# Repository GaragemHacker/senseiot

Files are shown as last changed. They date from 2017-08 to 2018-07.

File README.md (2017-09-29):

senseiot
========

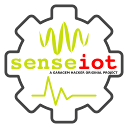
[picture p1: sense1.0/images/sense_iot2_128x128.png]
(https://github.com/Garagem-Hacker/senseiot/)
.

Sense IoT é um projeto para pesquisa e desenvolvimento de uma rede de sensores sem fio.

Sensores
--------

* **ht**: Umidade e temperatura.
* **sound**: Som.
* **presence**: Presença.
* **gas**: Gás.
* **rain**: Chuva.

ESP8266
-------

Vamos utilizar o ESP8266 neste projeto.
Veja o wiki para uma introdução ao
[ESP8266](https://github.com/Garagem-Hacker/senseiot/wiki).

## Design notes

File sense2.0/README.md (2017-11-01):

Senseiot 2.0
============
Nova Versão de Sense IoT

(https://github.com/Garagem-Hacker/senseiot/).

Sense IoT é um projeto para pesquisa e desenvolvimento de uma rede de sensores sem fio.

Hardware
--------
* **ESP8266**: Nó IoT;
* **Raspberry**: Gateway IoT;
* **ht05**: Sensor de Umidade e Temperatura;
* **sct**: Sensor de Corrente Elétrica;
* **ASQ/Ctrl-Board**: Aquisição de corrente e Comandos elétricos.
* NodeMCU: Nó Lora com sensores BMP085 e TSL2561.

Software
--------
* **API**: Da acesso do banco de dados ao Servidor Mathematica
* **Crypto**: Encript/Decrypt Payload
* **Docker**: Docker Containers
* **Mathematica**: Computer Algebra System (CAS) para Analytics dos dados
* **WebPage**: Visualização dos dados coletados e comandos para controle.

Ferramentas
-----------
* **BrokerMQTT**: Servidor IoT MQTT
* **Flask**: Microframework para aplicação Web
* **Docker**: Docker Containers
* **Crypto**: Rotinas para Criptografar/Decriptografar dados

Estrutura MQTT
--------------
Regra de comunicação dos tópicos MQTT para os dispositivos

/*		   MQTT Topic Struct

 	    'dev/node1/current2'
		|    |     |
		|    |     |
  	device(dev)  |    variable to sub/pub 
  		or   | (led1..n,temp1...n,button1...n)
 		     |
	command(cmd) |
 		     |
	IoT device node (node1...n)

*/

 Em resumo:
* Classe dispositivos(dev) ou comandos (cmd)
* Nó IoT em Questão (node1,..n)
* Variavel de Controle/Comandos (led1, button2, temp1, ...)

Dockers Containers
------------------
* **dMosquitto**: Mosquitto MQTT
* **dFlask**: Servico Backend
...

Referências 
-----------

 * [ESP8266](https://github.com/Garagem-Hacker/senseiot/wiki) - Utilização do ESP8266;
 * [ESP8266-&-MQTT](https://github.com/edgarreis/ESP8266-MQTT-Arduino) - Utilização do MQTT no ESP8266;
 * [MQTT-Python-Web](https://douglaszuqueto.com/artigos/integrando-a-aplicacao-web-com-banco-de-dados) - Integrando a aplicação MQTT à web com banco de dados;

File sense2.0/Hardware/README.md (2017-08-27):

senseiot
========

Placas de Monitoramento de Consumo e Comando.

Schematic
-------
***CurrentMeasBoard**

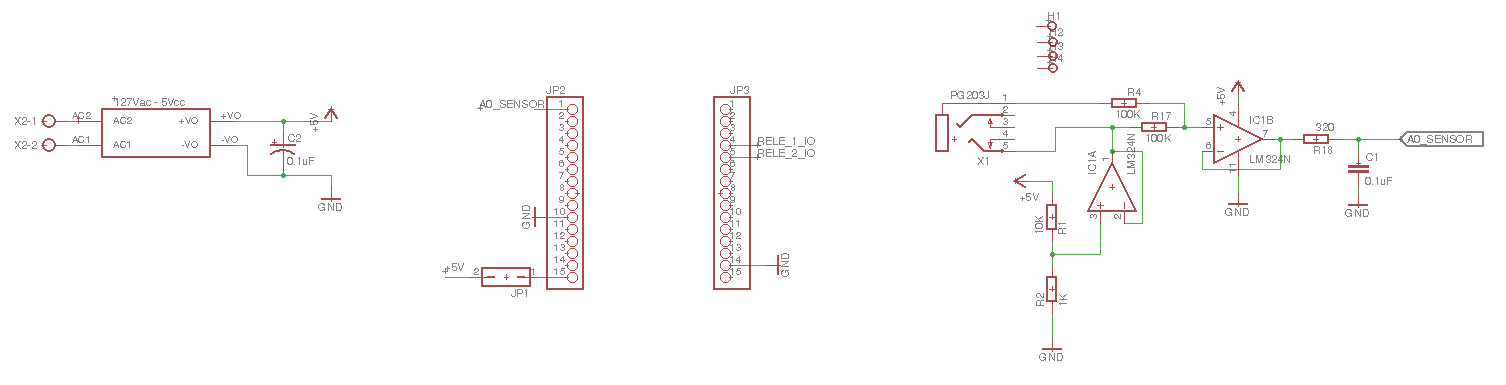
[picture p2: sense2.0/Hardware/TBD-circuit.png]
(https://github.com/Garagem-Hacker/senseiot/)


***RelesBoard**

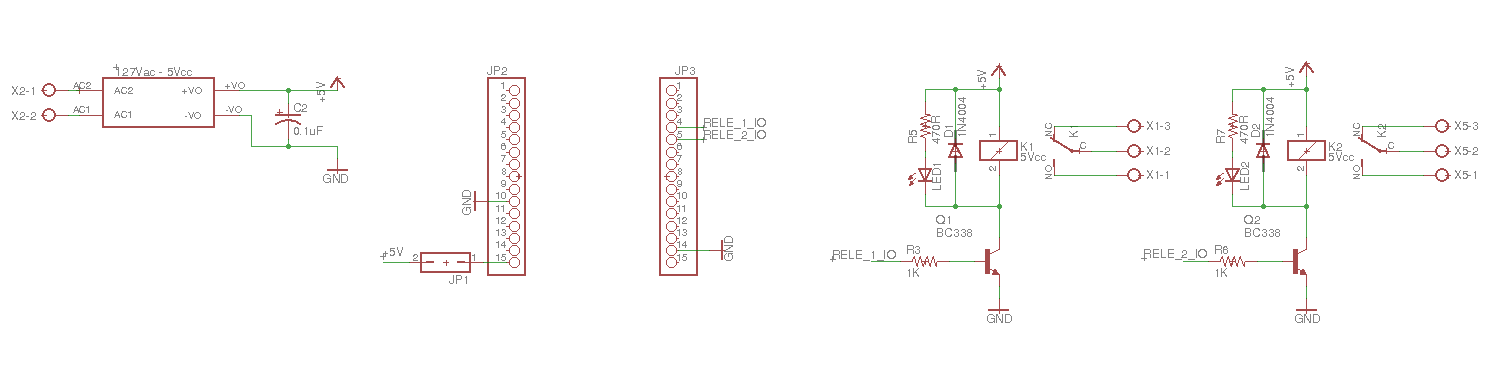
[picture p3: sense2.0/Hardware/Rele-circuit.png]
(https://github.com/Garagem-Hacker/senseiot/)


Board
-----

***CurrentMeasBoard**

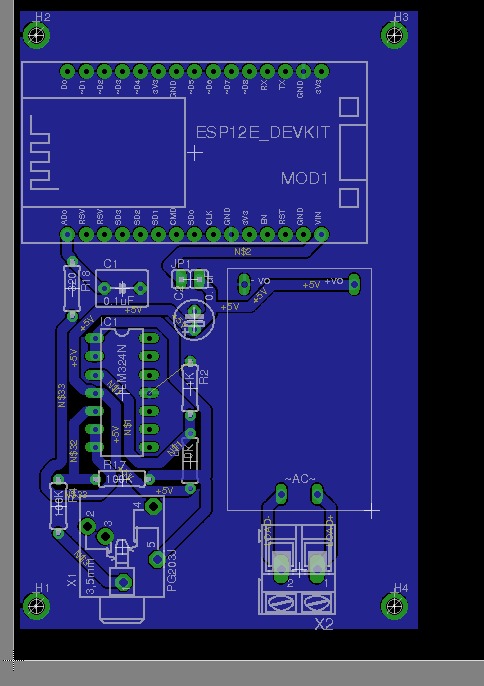
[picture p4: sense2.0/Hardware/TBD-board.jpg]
(https://github.com/Garagem-Hacker/senseiot/)


***RelesBoard**

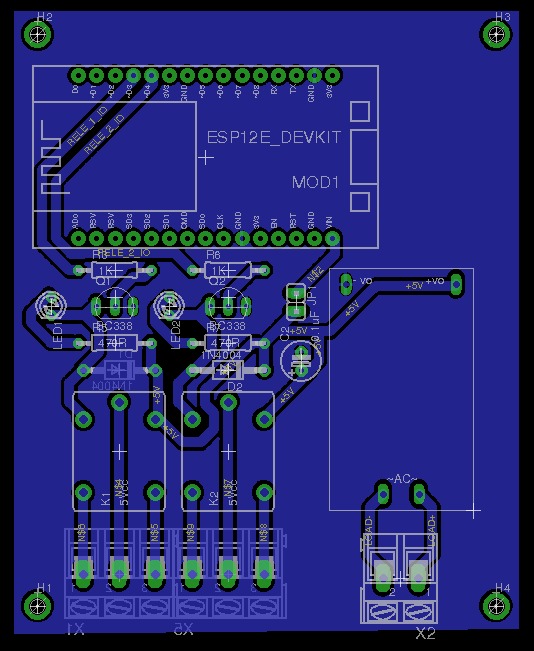
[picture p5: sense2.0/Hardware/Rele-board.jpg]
(https://github.com/Garagem-Hacker/senseiot/)


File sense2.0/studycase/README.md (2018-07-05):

### StudyCase

This is the iot.garagemhacker.org which wee have present a simple use case of IOT's Up and Running  
with a go website desplaying grafs of a set o sensors controled by a bunch of ESP8266 nodeMcu nodes.
  
Deploy me with traefik as a rev-proxy then compose me up. :wink:  
Enjoy

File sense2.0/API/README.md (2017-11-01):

# API para Acesso dos dados do Banco de Dados
-------------------

Funcionalidades
---------------

* **create_table.py** Cria as Tabelas do SQLite

* **database.db** Database em SQLite que persiste os dados trocados entre o MQTT e a API 

* **subscriber.py** Descontinuado (~~Subscreve nos Tópicos MQTT e salva os dados no Banco de Dados~~)

* **publish_subscribe.py** Subscreve nos Tópicos MQTT e salva os dados no Banco de Dados, além de Publicar os dados novos no banco de dados que são recebidos pela API

* **rest_flask.py** Descontinuado (~~Coleta do banco os dados e repassa via método GET, Informações: Temperatura~~)

* **rest_flask2.py** Descontinuado (~~Coleta do banco os dados e repassa via método GET, Informações: Temperatura e Corrente~~)

* **restful_flask.py** API - Coleta do banco os dados e repassa via método GET, além de receber os dados vai método POST. Informações: Temperatura, Corrente, Comando (Separados via nós).

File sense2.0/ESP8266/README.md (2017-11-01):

# ESP8266 Codes
-------------------

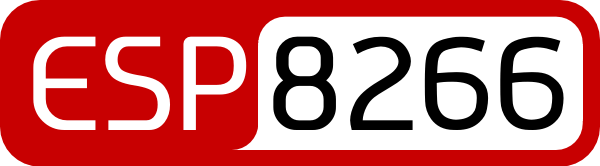
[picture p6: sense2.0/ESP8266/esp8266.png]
(https://github.com/Garagem-Hacker/senseiot/)
.

* **CurrentMeas.ino** Faz Medições de Corrente com Sct-013-100 

* **Dht22_mqtt.ino** Faz Medições de Temperatura e Umidade com o DHT22

* **Reles_mqtt.ino** Atua em dispositivos ON/OFF

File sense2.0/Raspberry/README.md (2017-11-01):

# Raspberry
-------------

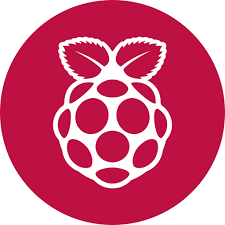
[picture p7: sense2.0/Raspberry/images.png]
(https://github.com/Garagem-Hacker/senseiot/)
.

Códigos para o Gateway IoT Raspberry
-----------------------------------
Módulos
-------
* **Mathematica** Analytics;
* **Mosquitto** MQTT;
* **MSQL** Server;

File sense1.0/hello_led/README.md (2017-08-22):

hello led
=========

Um hello world usando LED e ESP8266

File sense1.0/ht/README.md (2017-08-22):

ht
==

Sensor de umidade e temperatura.

Dependência
-----------

* https://github.com/adafruit/DHT-sensor-library

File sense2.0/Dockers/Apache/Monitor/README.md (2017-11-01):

# tempmonitor

A simple web interface which subscribes to an MQTT topic branch to
display the information from a temperature sensor.

The sensor is an Arduino which publishes a `1` when it comes online to the topic:

```
'dev/node1/led1'
```

and which otherwise publishes an integer to the

```
'dev/node1/temperature'
```

topic.

The brunt of the work (design, layout, etc.) was based from [mqtt-panel](https://github.com/fabaff/mqtt-panel), written by Fabian Affolter.

The screenshot shows an example:

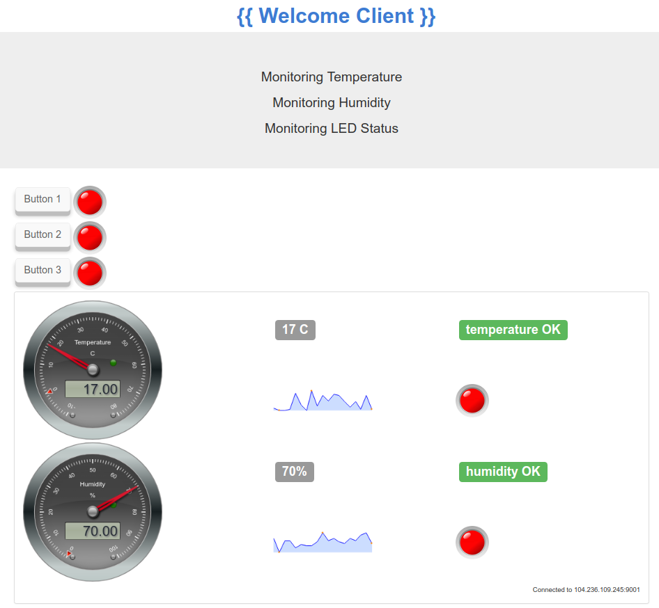
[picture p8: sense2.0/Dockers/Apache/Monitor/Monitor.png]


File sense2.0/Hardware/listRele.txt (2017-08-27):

Partlist

Exported from Rele-board.sch at 25/08/17 11:49

EAGLE Version 8.3.1 Copyright (c) 1988-2017 Autodesk, Inc.

Assembly variant: 

Part     Value                Device               Package       Library        Sheet

C2       0.1uF                CPOL-USE2.5-6        E2,5-6        rcl            1
D1       1N4004               1N4004               DO41-10       diode          1
D2       1N4004               1N4004               DO41-10       diode          1
FONTE    HLK-PM01             HLK-PM01             HLK-PM01      hlk-pm01       1
H1       SPECIAL_DRILL_0.1000 SPECIAL_DRILL_0.1000 PAD_0.1000    special-drill  1
H2       SPECIAL_DRILL_0.1000 SPECIAL_DRILL_0.1000 PAD_0.1000    special-drill  1
H3       SPECIAL_DRILL_0.1000 SPECIAL_DRILL_0.1000 PAD_0.1000    special-drill  1
H4       SPECIAL_DRILL_0.1000 SPECIAL_DRILL_0.1000 PAD_0.1000    special-drill  1
JP1                           JP1Q                 JP1           jumper         1
K1       5Vcc                 CQ1-12V              CQ1           relay          1
K2       5Vcc                 CQ1-12V              CQ1           relay          1
LED1                          LED3MM               LED3MM        led            1
LED2                          LED3MM               LED3MM        led            1
MOD1     ESP12E_DEVKIT        ESP12E_DEVKIT        ESP12E_DEVKIT ESP12E_DEVKIT  1
Q1       BC338                BC338                TO92-EBC      transistor-npn 1
Q2       BC338                BC338                TO92-EBC      transistor-npn 1
R3       1K                   R-US_0207/10         0207/10       rcl            1
R5       470R                 R-US_0207/10         0207/10       rcl            1
R6       1K                   R-US_0207/10         0207/10       rcl            1
R7       470R                 R-US_0207/10         0207/10       rcl            1
X1                            AK300/3              AK300/3       con-ptr500     1
X2                            AK300/2              AK300/2       con-ptr500     1
X5                            AK300/3              AK300/3       con-ptr500     1

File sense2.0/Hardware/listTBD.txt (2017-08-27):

Partlist

Exported from TBD-board.sch at 25/08/17 11:49

EAGLE Version 8.3.1 Copyright (c) 1988-2017 Autodesk, Inc.

Assembly variant: 

Part     Value                Device               Package       Library        Sheet

C1       0.1uF                C5/5                 C5B5          capacitor-wima 1
C2       0.1uF                CPOL-USE2.5-6        E2,5-6        rcl            1
FONTE    HLK-PM01             HLK-PM01             HLK-PM01      hlk-pm01       1
H1       SPECIAL_DRILL_0.1000 SPECIAL_DRILL_0.1000 PAD_0.1000    special-drill  1
H2       SPECIAL_DRILL_0.1000 SPECIAL_DRILL_0.1000 PAD_0.1000    special-drill  1
H3       SPECIAL_DRILL_0.1000 SPECIAL_DRILL_0.1000 PAD_0.1000    special-drill  1
H4       SPECIAL_DRILL_0.1000 SPECIAL_DRILL_0.1000 PAD_0.1000    special-drill  1
IC1      LM324N               LM324N               DIL14         linear         1
JP1                           JP1Q                 JP1           jumper         1
MOD1     ESP12E_DEVKIT        ESP12E_DEVKIT        ESP12E_DEVKIT ESP12E_DEVKIT  1
R1       10K                  R-EU_0207/7          0207/7        resistor       1
R2       1K                   R-EU_0207/7          0207/7        resistor       1
R4       100K                 R-EU_0207/7          0207/7        resistor       1
R17      100K                 R-EU_0207/7          0207/7        resistor       1
R18      320                  R-EU_0207/7          0207/7        resistor       1
X1       PG203J               PG203J               PG203J        con-hirschmann 1
X2                            AK300/2              AK300/2       con-ptr500     1

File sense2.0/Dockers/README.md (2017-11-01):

# CONTAINERS
-------------

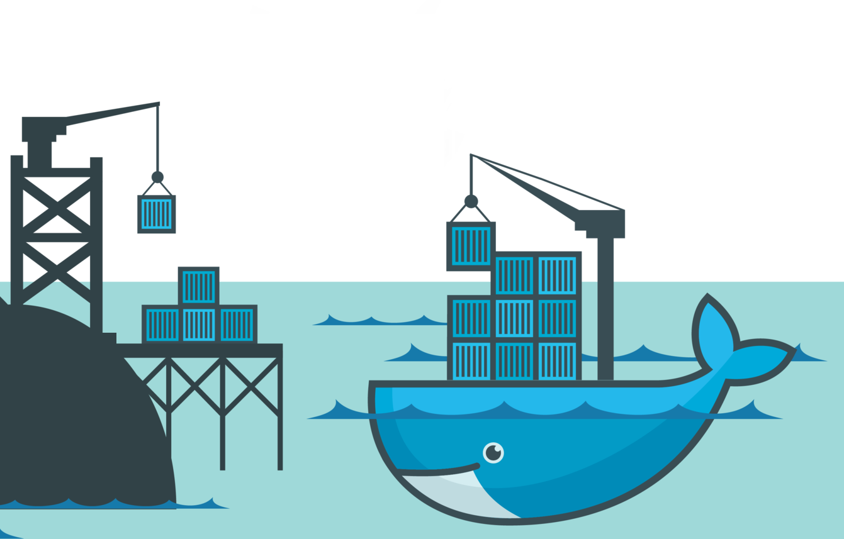
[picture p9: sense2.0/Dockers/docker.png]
(https://github.com/Garagem-Hacker/senseiot/)
.

* **API** container;
* **Apache** Web;
* **Mosquitto** MQTT;
* **MSQL** Server;

* **API** container;
Criação uma API RestFUL em Python;

[REF - building-a-basic-restful-api-in-python](https://www.codementor.io/sagaragarwal94/building-a-basic-restful-api-in-python-58k02xsiq);

[REF - como-criar-uma-api-restful-agil-e-escalavel-com-python](http://www.programadorlivre.com/como-criar-uma-api-restful-agil-e-escalavel-com-python-parte-1/);

* **APACHE** container;

Criação do Servidor com utilização da pasta do host no container:

docker run -p 80:80 -p 443:443 -v /var/www/html/ -:/var/www/html/ -d eboraas/apache

* **MOSQUITTO** container;

Cria um container Mosquitto completo para configuração posterior

docker run -ti -p 1883:1883 -p 9001:9001 toke/mosquitto
docker exec -it dMosquitto /bin/bash

* **MSQL** Server;

Cria um container MySQL para Acesso Externo dos dados

docker run --name mysql-container -p 3306:3306 -v /home/zulu/datadir:/var/lib/mysql -e MYSQL_ROOT_PASSWORD=mysql-server MYSQL_ROOT_HOST=% -d mysql/mysql-server:latest

------------------

* **Arvore dos Containers**

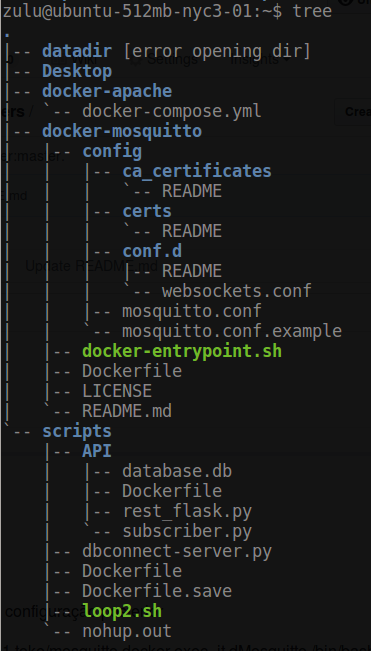
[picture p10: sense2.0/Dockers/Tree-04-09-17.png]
(https://github.com/Garagem-Hacker/senseiot/)
.

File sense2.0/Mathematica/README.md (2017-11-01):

# Mathematica Codes
-------------------

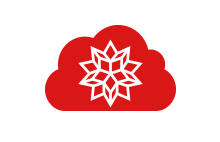
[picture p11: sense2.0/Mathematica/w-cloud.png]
(https://github.com/Garagem-Hacker/senseiot/)
.

* **GetServer.nb** Conecta o Mathematica a Servidor MySQL pela Porta 3306

* **API.nb** Conecta o Mathematica a API Python criada na Porta 5002

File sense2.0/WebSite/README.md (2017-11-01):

# WebSite
-------------------

ScreenShot
[[ Meter.zip contem os arquivos para executar este Front-end]]

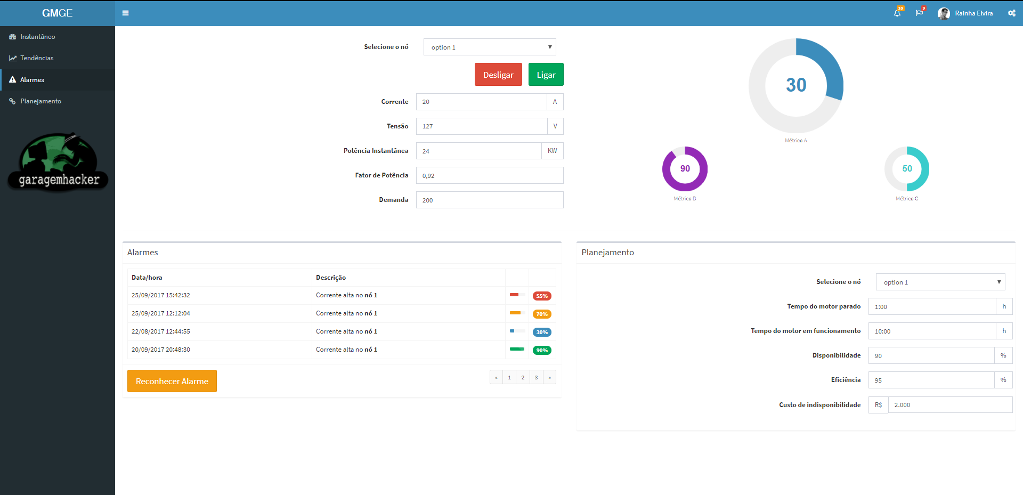
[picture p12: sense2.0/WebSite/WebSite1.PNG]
(http://echo1001.me/meter/)
.
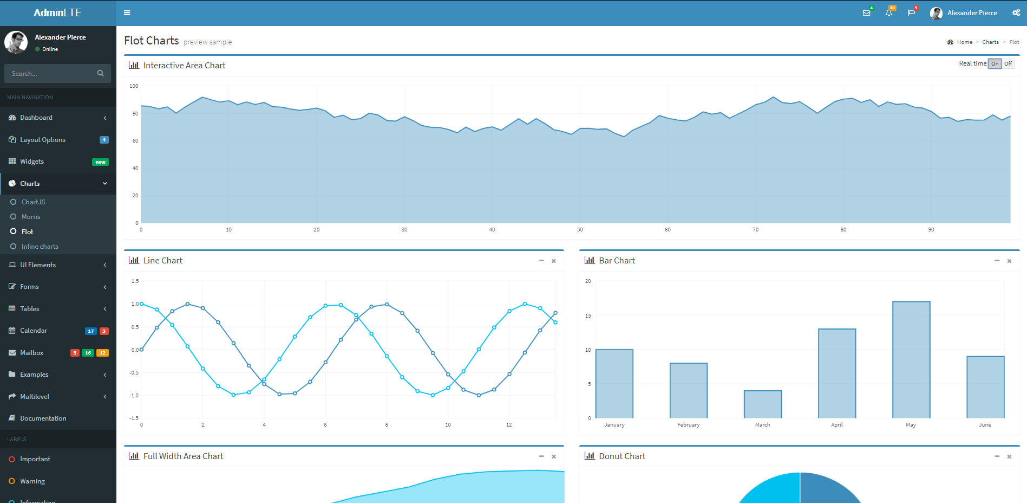
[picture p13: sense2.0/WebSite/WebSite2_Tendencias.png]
(http://secondway.com.br/garagem-dashboard/adminLTE/pages/charts/flot.html)
.

WebSite para visualização dos dados coletados e comandos para controle.

Monitoramento e Gestão de Energia
---------------
Funcionalidades
---------------

* **Login** Tela de login de acesso ao iniciar

* **Instantaneo** Tela de medição dos valores obtidos instantaneamente *(Prioridade 1)*.

  > Medições: Corrente, Tensão, Potencia Instantanea, Fator de Potencia, Demanda
  > Esses dados podem ser obtidos com a atualização do ultimo valor de cada tabela do banco de dados.

* **Tendências** Tela de tendencias das variaveis analógicas *(Prioridade 2)*.
  > Tensão 
  > Corrente

* **Alarmes** Tela de Alarmes para monitoramente de valores acima e/ou abaixo de setpoints prédeterminados *(Prioridade 3)*.
  > Conter Tabela: Horário, Descritivo, Valor

* **Planejaemento** Tela de Planejamento *(Prioridade 4)*

contendo dados como: 
  > Tempo de equipamento parado
  > Tempo de equipamento funcionando
  > Disponibilidade
  > Eficiencia
  > Custo de indisponibilidade
  > Padrão de consumo

Banco de Dados
---------------

Tabelas Populadas

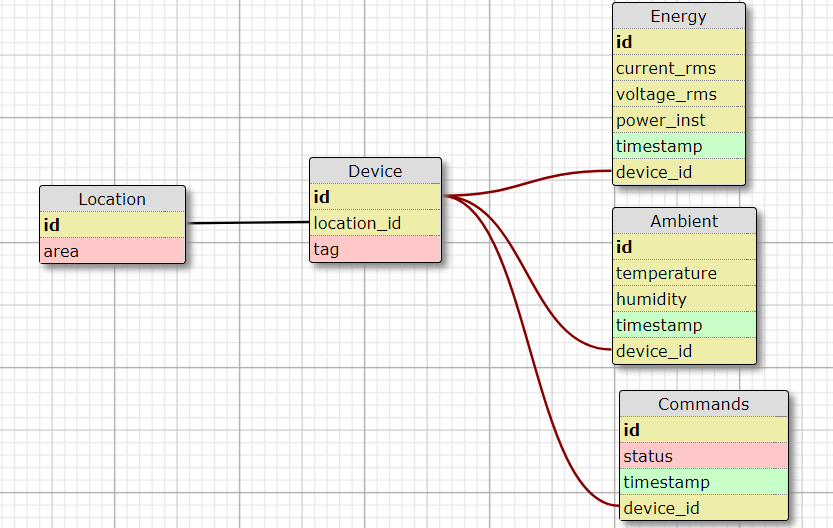
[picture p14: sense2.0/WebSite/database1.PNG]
[].

Referências 
-----------

 * [GaragemDashboard](http://secondway.com.br/garagem-dashboard/i) - Modelo utilizado;
 * [adminlte](https://adminlte.io/docs/2.4/license) - adminlte license;
 * [charts](http://secondway.com.br/garagem-dashboard/adminLTE/pages/charts/flot.html) - Charts para Tendencias;
 
 * [Flask JSONDashs](https://github.com/christabor/flask_jsondash) - Flask JSONDashs;
 
 * [dashboard](https://github.com/anapaulagomes/dashboard) - Dashboard usando Python + Flask + DC.js;
 * [realpython](https://realpython.com/blog/python/the-ultimate-flask-front-end/) - The Ultimate Flask Front-End;
 * [dash](https://plot.ly/products/dash/) - Build beautiful web-based interfaces in Python;
 
 * [adilmoujahid](http://adilmoujahid.com/posts/2015/01/interactive-data-visualization-d3-dc-python-mongodb/) - Interactive Data Visualization with D3.js, DC.js, Python, and MongoDB;

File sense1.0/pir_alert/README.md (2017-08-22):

pir alert -> ESP8266 + NodeMCU + Lua + MQTT = FUN ;)
=========

Introdução

Lua é uma linguagem um pouco familiar então resolvi testá-la com o ESP8266.
Para isso segui os passos do Augusto Campos e instalei o NodeMCU na minha
placa conforme o link http://br-arduino.org/2015/08/nodemcu-esp8266.html.
O processo é rápido e simples, necessita de alguns passos mas nada demais.
A nota que fica dessa primeira parte, é importante selecionar a opcao MQTT
na ferramenta http://frightanic.com/nodemcu-custom-build/ quando for escolher
os modulos a serem compilados.

Objetivo

Testar a integração da placa ESP8266 com NodeMCU e um broker MQTT. Neste
exemplo vou simular que o pino 2 da placa esta conectado a um sensor PIR,
poderia ser qualquer outro sensor digital como por exemplo um reed switch.

Para este exemplo usei os seguintes itens:

SW e HW
- placa ESP8266
- fonte alimentação 3.3V
- jumpers
- cabo serial ou conversor usb/serial
- conta no cloudmqtt.com
- teraterm ou coolterm ou outra ferramenta para acesso a serial
- luatool, disponivel em https://github.com/4refr0nt/luatool
- Python + Serial

Funcionamento

1) Execute os passos conforme o link do BR-Arduino para colocar o NodeMCU na
sua placa ESP. Atenção para a configuração dos pinos de IO pois são necesários
para atualizar o firmware da sua placa. Use os jumpers para mudar o estado dos
pinos. Depois de colocar o NodeMCU para rodar configure o pinos para:

RX e TX conectados no seu conversor, pode ser um modulo FTDI para ligar no PC.
CH_PH setao para HIGH
GPIO_0 setado para HIGH
GPIO_2 conectados no GND
RST conectado no GND

O pino GPIO_2 será usado para simular o comportamento de um sensor de presença,
por isso é legal deixar um jumper conectado nesse pino para poder mudar de HIGH
para LOW e para HIGH.

2) Crie uma conta no serviço https://www.cloudmqtt.com, é rápido e gratuito
para conexões de teste. Veja os planos que eles comercializam em 
https://www.cloudmqtt.com/plans.html Escolhi para este teste a opção Cute Cat.

3) Baixe o código exemplo pir_alert.lua e altere as variáveis de configuração
abaixo. Link para o código https://github.com/devlware/senseiot/blob/master/pir_alert/pir_alert.lua

Configure o ID e senha para seu roteador.
ssid = "id_roteador"
ssid_passwd = "senha_rede_wifi"

Indique um id para identificação da sua placa, pode ser qualquer texto.
m_id = "algum_id"

Preencha o usuário e senha com os dados obtidos na conta do cloudmqtt.
m_user = "user_cloudmqtt"
m_pass = "pass_cloud_mqtt"

Salve o arquivo, mantenha o nome como pir_alert.lua.

4) Pronto, agora você precisa enviar esse arquivo lua para a sua placa. Ele será
executado toda vez que a placa for alimentada ou reiniciada.
Use a ferramenta luatool baixada anteriormente para enviar o arquivo para sua
placa. O comando no Mac/Linux deve ser:
Substitua tty.usbserial pelo id do dispositivo serial usado.

./luatool.py --port /dev/tty.usbserial --src pir_alert.lua --dest init.lua --verbose

5) Agora remova a energia da placa, use seu programa preferido para abrir a porta
serial onde a ESP esta conectada. Ligue a alimentação da placa, você deve ver algumas
informações sendo exibidas no console Lua.

6) Aguarde alguns segundos, o ip, máscara e Mac da sua placa devem ser impressos
no console.

7) Depois uma mensagem deve informar que a conexão com o broker MQTT foi concluida.

8) Faça o login na sua conta no cloudmqtt e acesse Websocket UI.
https://api.cloudmqtt.com/sso/cloudmqtt/websocket Aqui você poderá ver o tópico
sendo publicado quando o pino 2 da sua placa mudar de LOW para HIGH.

9) Pronto, agora você pode testar seu setup. Mude o status do pino 2 (GPIO_2) de
LOW para HIGH. A mensagem "alerta intruso enviado" deve ser exibida na linha de
comando do Lua e uma entrada com topico alert/pir e mensagem 1 deve ser exibida
na tela de controle do cloudmqtt (Websocket UI).

TODO
- Monitorar pino do pir por um com interrupção.
- Botar a placa para dormir e acordar com a interrupção para economizar energia.
- Medir consumo da placa usando baterias.

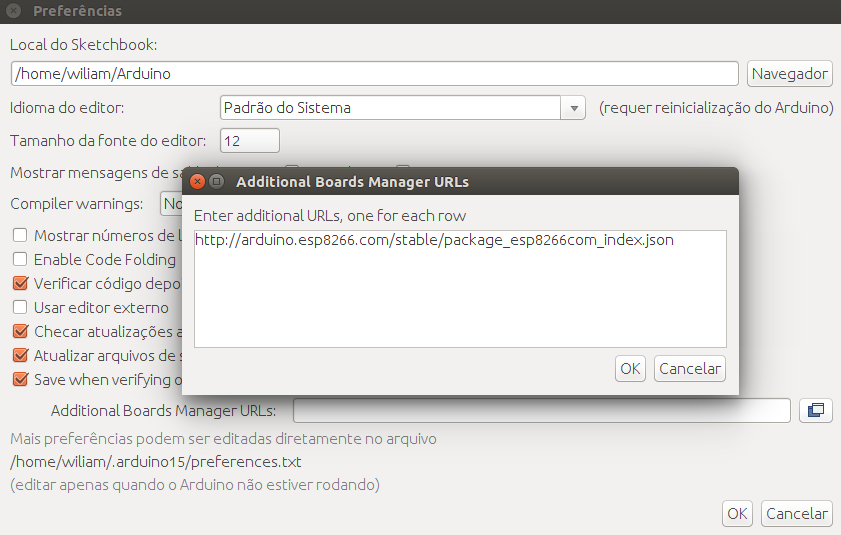
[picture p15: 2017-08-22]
sense1.0/images/preferencias.png

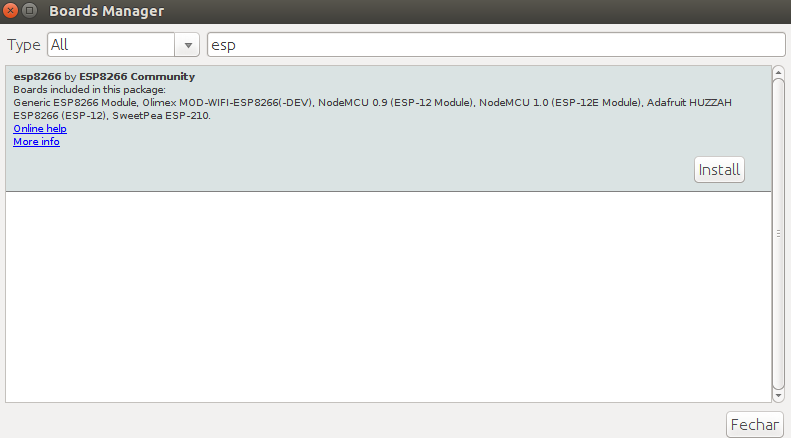
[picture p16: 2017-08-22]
sense1.0/images/manager.png

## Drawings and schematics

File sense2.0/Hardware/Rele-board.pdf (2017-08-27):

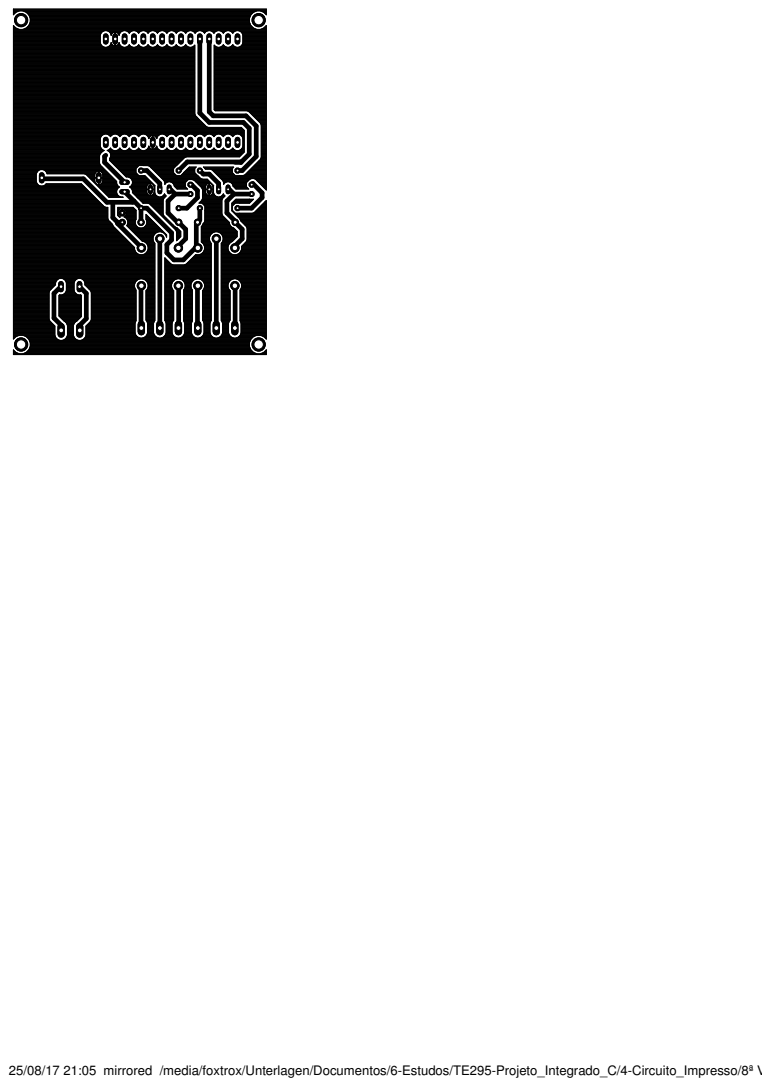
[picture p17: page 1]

25/08/17 21:05 mirrored /media/foxtrox/Unterlagen/Documentos/6-Estudos/TE295-Projeto_Integrado_C/4-Circuito_Impresso/8ª Versão/Rele-board.brd

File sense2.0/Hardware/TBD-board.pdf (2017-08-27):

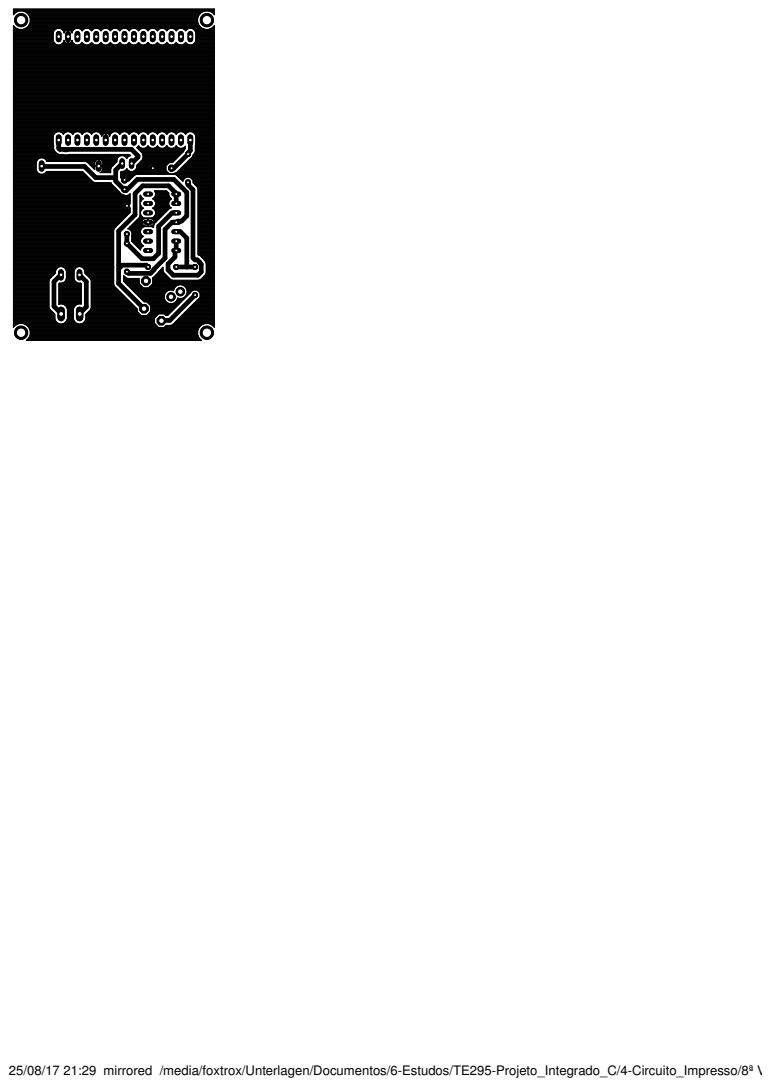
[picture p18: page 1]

25/08/17 21:29 mirrored /media/foxtrox/Unterlagen/Documentos/6-Estudos/TE295-Projeto_Integrado_C/4-Circuito_Impresso/8ª Versão/TBD-board.brd

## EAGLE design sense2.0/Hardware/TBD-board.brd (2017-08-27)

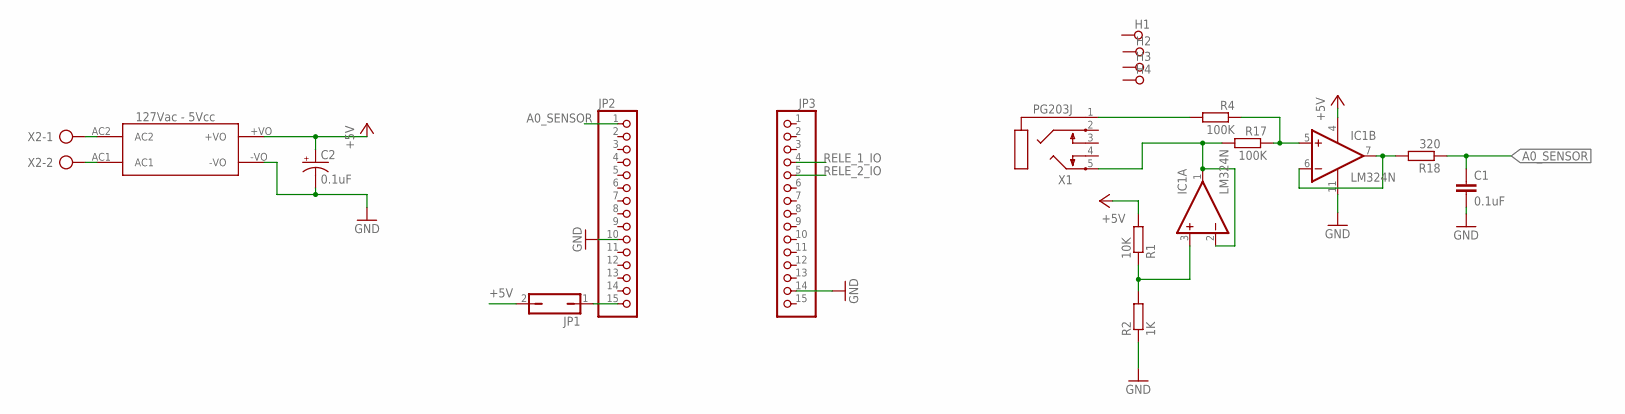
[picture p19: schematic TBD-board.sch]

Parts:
C1: 0.1uF; C5B5
C2: 0.1uF; E2,5-6
FONTE: HLK-PM01
H1, H2, H3, H4: SPECIAL_DRILL_0.1000; PAD_0.1000
IC1: LM324N; DIL14
JP1: JP1Q; JP1
JP2, JP3: PINHD-1X15; 1X15
R1: 10K; 0207/7
R2: 1K; 0207/7
R4, R17: 100K; 0207/7
R18: 320; 0207/7
X1: PG203J
X2: AK300/2

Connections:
+5V: C2.+, FONTE.+VO, IC1.4 (V+), JP1.2, R1.2
A0_SENSOR: C1.1, JP2.1, R18.1
GND: C1.2, C2.-, FONTE.-VO, IC1.11 (V-), JP2.10, JP3.14, R2.1
LOAD+: FONTE.AC2, X2.1
LOAD-: FONTE.AC1, X2.2
unnamed: IC1.3 (+IN), R1.1, R2.2
unnamed: JP1.1, JP2.15
unnamed: R4.2, X1.1
unnamed: IC1.5 (+IN), R4.1, R17.1
unnamed: IC1.6 (-IN), IC1.7 (OUT), R18.2
RELE_1_IO: JP3.4
RELE_2_IO: JP3.5
SENSOR-A-2: IC1.1 (OUT), IC1.2 (-IN), R17.2, X1.5

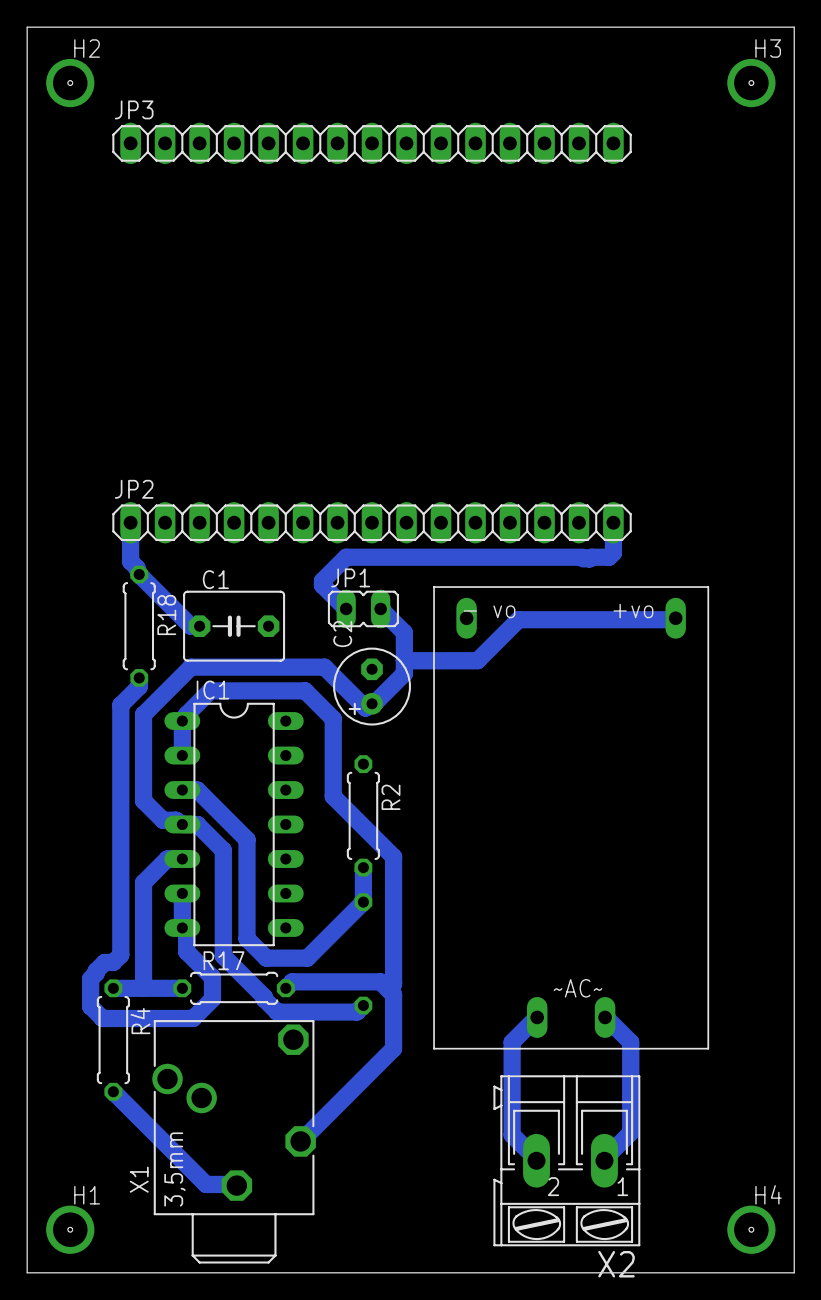
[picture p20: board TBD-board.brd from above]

Board: 2 copper layers, 56.5 x 91.7 mm, 18 parts (1 on the bottom side), 11 nets.

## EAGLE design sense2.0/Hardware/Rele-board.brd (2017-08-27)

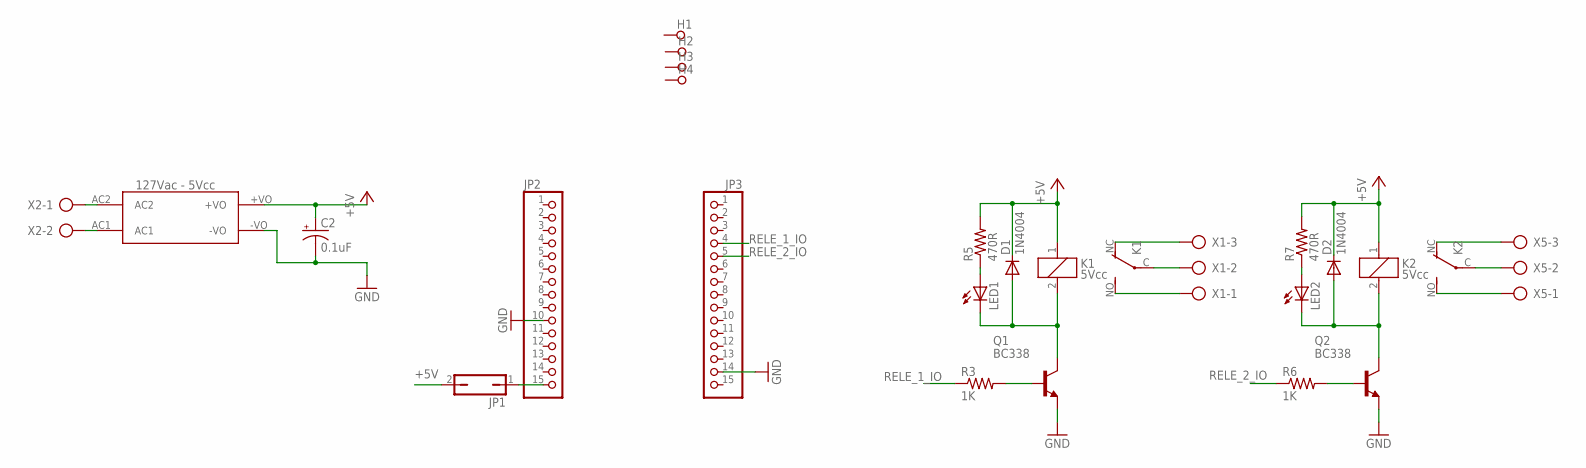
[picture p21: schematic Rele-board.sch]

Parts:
C2: 0.1uF; E2,5-6
D1, D2: 1N4004; DO41-10
FONTE: HLK-PM01
H1, H2, H3, H4: SPECIAL_DRILL_0.1000; PAD_0.1000
JP1: JP1Q; JP1
JP2, JP3: PINHD-1X15; 1X15
K1, K2: 5Vcc; CQ1
LED1, LED2: LED3MM
Q1, Q2: BC338; TO92-EBC
R3, R6: 1K; 0207/10
R5, R7: 470R; 0207/10
X1, X5: AK300/3
X2: AK300/2

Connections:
+5V: C2.+, D1.C, D2.C, FONTE.+VO, JP1.2, K1.1, K2.1, R5.2, R7.2
GND: C2.-, FONTE.-VO, JP2.10, JP3.14, Q1.E, Q2.E
LOAD+: FONTE.AC2, X2.1
LOAD-: FONTE.AC1, X2.2
unnamed: JP1.1, JP2.15
unnamed: K1.C, X1.2
unnamed: K1.NC (O), X1.3
unnamed: K1.NO (S), X1.1
unnamed: K2.C, X5.2
unnamed: K2.NC (O), X5.3
unnamed: K2.NO (S), X5.1
unnamed: Q2.B, R6.2
unnamed: LED2.A, R7.1
unnamed: D2.A, K2.2, LED2.K (C), Q2.C
unnamed: Q1.B, R3.2
unnamed: LED1.A, R5.1
unnamed: D1.A, K1.2, LED1.K (C), Q1.C
RELE_1_IO: JP3.4, R3.1
RELE_2_IO: JP3.5, R6.1

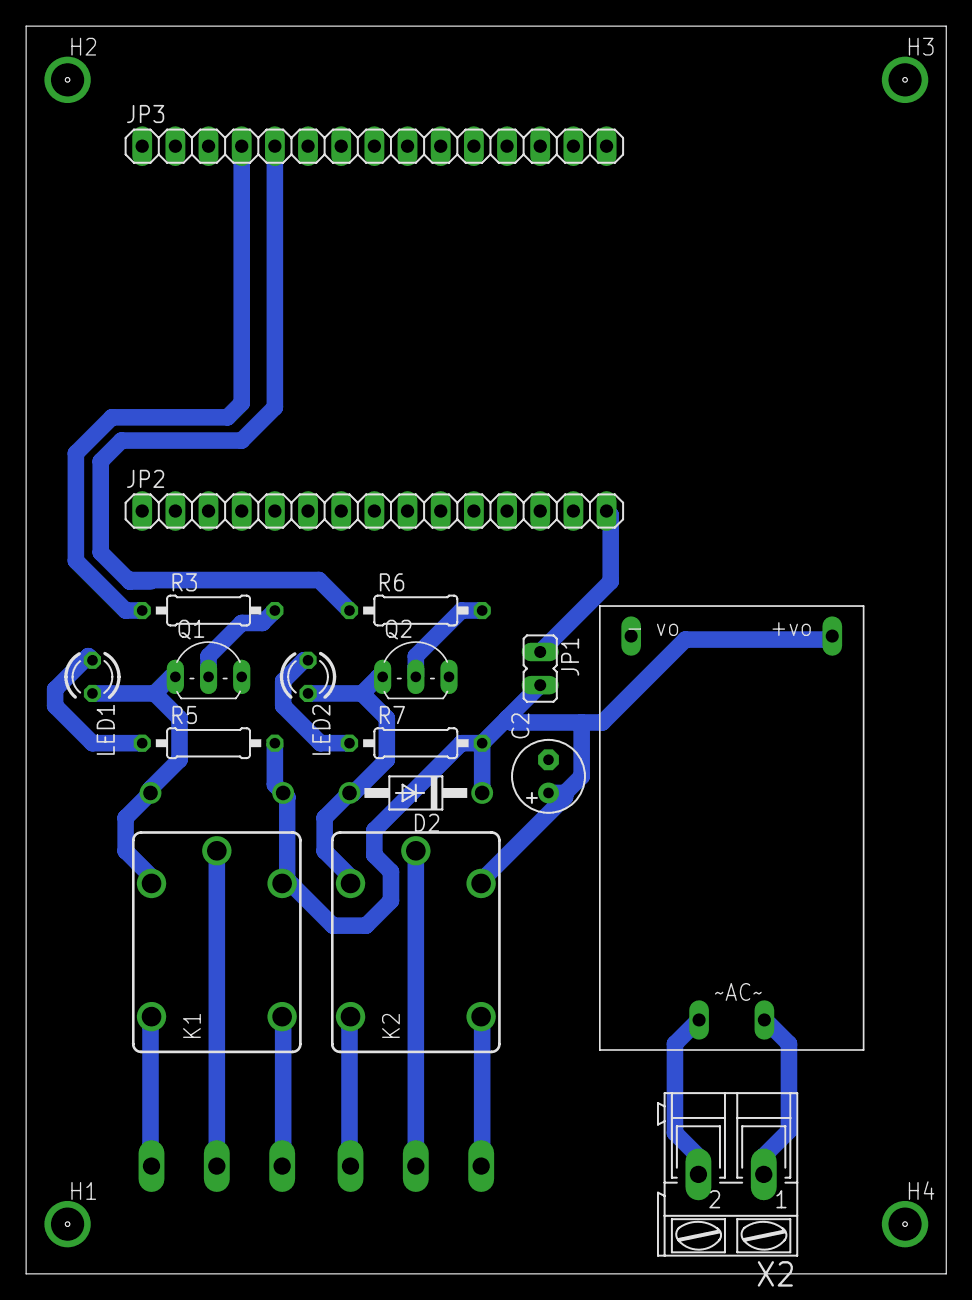
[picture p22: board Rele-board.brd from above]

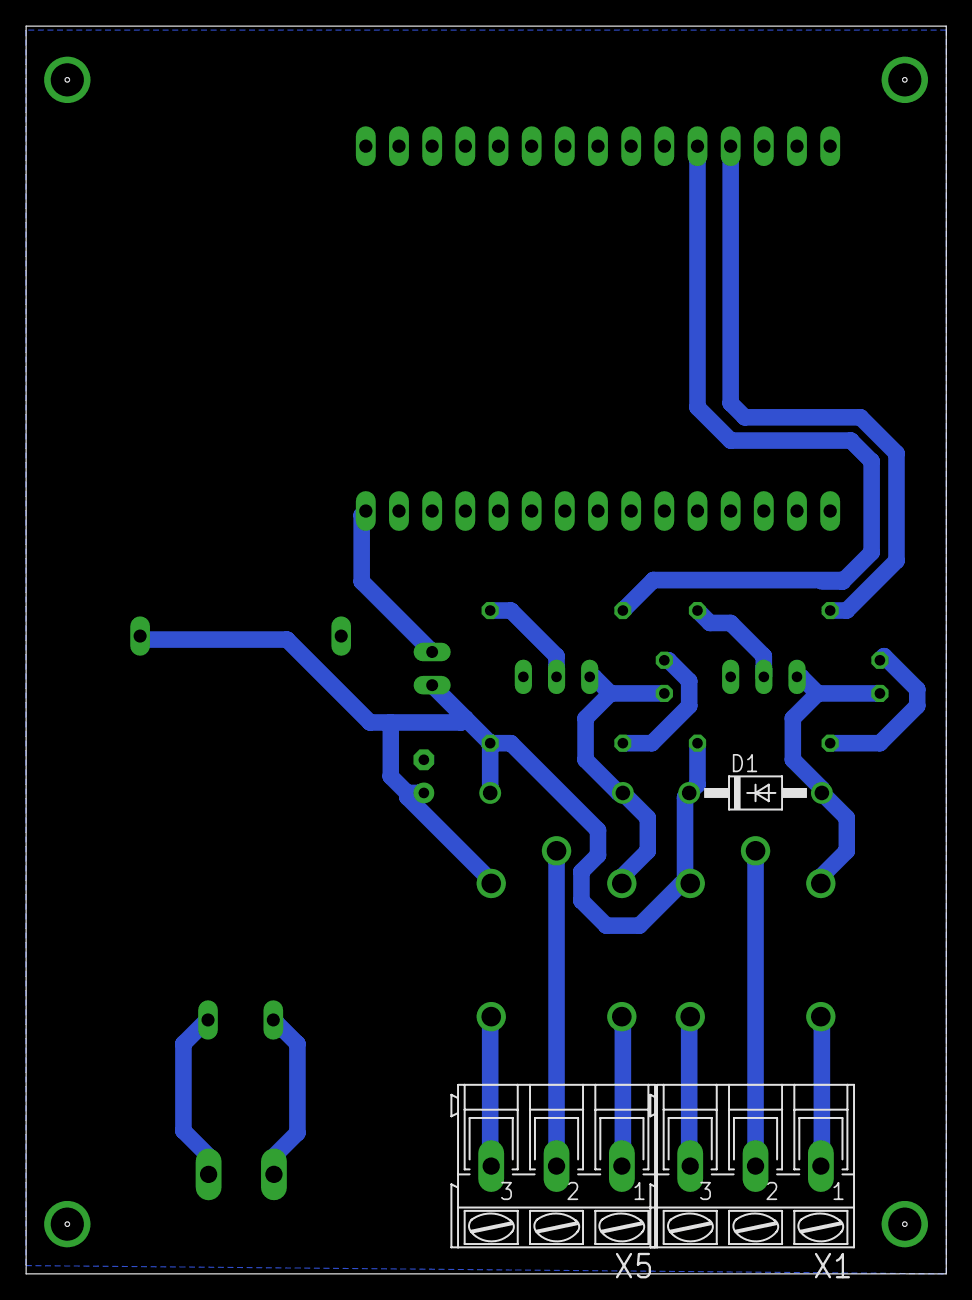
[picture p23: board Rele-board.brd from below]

Board: 2 copper layers, 70.5 x 95.6 mm, 24 parts (3 on the bottom side), 19 nets.

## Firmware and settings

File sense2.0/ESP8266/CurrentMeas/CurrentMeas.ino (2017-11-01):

#include <PubSubClient.h>
#include <ESP8266WiFi.h>
#include "EmonLib.h"
#include <ESP8266mDNS.h>
#include <WiFiUdp.h>
#include <ArduinoOTA.h>


#define REPORT_INTERVAL 1           // in sec

// Wifi SSID e Password
const char* ssid = "";     
const char* password = "";  

// Tópicos MQTT
char* hellotopic = "hello_topic"; 
char* topic = "dev/node1/current";
char* server = "";
int port = 1883;

// MQTT Client
String clientName;
WiFiClient wifiClient;
PubSubClient client(server, port, wifiClient);

// Medição
double Irms;
double Vrms = 127.00;
int cnt;

EnergyMonitor emon1;


// Converte mac to string
String macToStr(const uint8_t* mac){
  
    String result;

  for (int i = 0; i < 6; ++i) {

      result += String(mac[i], 16);

      if (i < 5)
          result += ':';
    }
    
    return result;
}

// Configurações
void setup(){


  //Comunicação Serial
  Serial.begin(115200);
  Serial.println("Booting");

  Serial.println();
  Serial.print("Connecting to ")  ;
  Serial.println(ssid);

  WiFi.mode(WIFI_STA);
  WiFi.begin(ssid, password);

  // Aguardando Conexão
  while (WiFi.status() != WL_CONNECTED) {
  
      delay(500);
      Serial.print(".");
  }

  // Conectado
  Serial.println("");
  Serial.println("WiFi connected");
  Serial.println("IP address: ");
  Serial.println(WiFi.localIP());

  // Cliente
  clientName += "esp8266-";
  uint8_t mac[6];
  WiFi.macAddress(mac);
  clientName += macToStr(mac);
  clientName += "-";
  clientName += String(micros() & 0xff, 16);

  // Conexão com o Servidor MQTT
  Serial.print("Connecting to ");
  Serial.print(server);
  Serial.print(" as ");
  Serial.println(clientName);

  if (client.connect((char*) clientName.c_str())) {
    
    Serial.println("Connected to MQTT broker");
    Serial.print("Topic is: ");
    Serial.println(topic);
          
  }else {
    Serial.println("MQTT connect failed");
    Serial.println("Will reset and try again...");
    abort();
  }

  // Configuração do EMONCS
  Serial.print("Configuring EMONCS");
  
  // Sensor de Corrente (input pin, calibration)
  emon1.current(A0, 19);        

  delay(20);


  // Configuração do OTA  
  // Port defaults to 8266
  ArduinoOTA.setPort(8266);

  // Hostname defaults to esp8266-[ChipID]
  ArduinoOTA.setHostname("Node1-Current");

  // No authentication by default
  ArduinoOTA.setPassword((const char *)"esp8266");

  ArduinoOTA.onStart([]() {
    Serial.println("Start");
  });
  ArduinoOTA.onEnd([]() {
    Serial.println("\nEnd");
  });
  ArduinoOTA.onProgress([](unsigned int progress, unsigned int total) {
    Serial.printf("Progress: %u%%\r", (progress / (total / 100)));
  });
  ArduinoOTA.onError([](ota_error_t error) {
    Serial.printf("Error[%u]: ", error);
    if (error == OTA_AUTH_ERROR) Serial.println("Auth Failed");
    else if (error == OTA_BEGIN_ERROR) Serial.println("Begin Failed");
    else if (error == OTA_CONNECT_ERROR) Serial.println("Connect Failed");
    else if (error == OTA_RECEIVE_ERROR) Serial.println("Receive Failed");
    else if (error == OTA_END_ERROR) Serial.println("End Failed");
  });
  ArduinoOTA.begin();
  Serial.println("Ready");
  Serial.print("IP address: ");
  Serial.println(WiFi.localIP());




  
}


// Principal
void loop(){
    
    // Verificação OTA update
    ArduinoOTA.handle();

    // Medição de Corrente (Calculo Irms)
    Irms = emon1.calcIrms(1480)-0.03;
    
    // Conversão double to String
    String payload = String(Irms,DEC);

    // Envio do Pacote MQTT
    sendPayload(payload, topic);
    
    cnt = REPORT_INTERVAL;

    // Temporização 1s
    while (cnt--)
      delay(1000);
}


// Envia MQTT Payload
void sendPayload(String payload, char* topic) {
  
  if (!client.connected()) {
    if (client.connect((char*) clientName.c_str())) {
      Serial.println("Connected to MQTT broker again");
      Serial.print("Topic is: ");
      Serial.println(topic);
    }
    else {
      Serial.println("MQTT connect failed");
      Serial.println("Will reset and try again...");
      abort();
    }
  }

  if (client.connected()) {
    Serial.print("Sending payload: ");
    Serial.println(payload);

    if (client.publish(topic, (char*) payload.c_str())) {
      Serial.println("Publish ok");
    }
    else {
      Serial.println("Publish failed");
    }
  }

}


// Manipula Mensagem Recebidas
void callback(char* topic, byte* payload, unsigned int length) {

  
}

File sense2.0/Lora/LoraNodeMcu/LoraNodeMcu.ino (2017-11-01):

#include <Adafruit_Sensor.h>
#include <Adafruit_BMP085_U.h>
#include <Adafruit_TSL2561_U.h>
#include <ESP.h>
#include <base64.h>

// All specific changes needed for ESP8266 need be made in hal.cpp if possible
// Include ESP environment definitions in lmic.h (lmic/limic.h) if needed
#include <lmic.h>
#include <hal/hal.h>
#include <SPI.h>
#include <Wire.h>
   
Adafruit_BMP085_Unified bmp = Adafruit_BMP085_Unified(10085);
Adafruit_TSL2561_Unified tsl = Adafruit_TSL2561_Unified(TSL2561_ADDR_FLOAT, 12345);

// LoRaWAN Application identifier (AppEUI)
static const u1_t APPEUI[8]  = { 0x40, 0x43, 0x45, 0x4E, 0x40, 0x00, 0x6F, 0x49 };

// LoRaWAN DevEUI, unique device ID (LSBF)
static const u1_t DEVEUI[8]  = { 0x4D, 0x40, 0x45, 0x46, 0x4F, 0xBE, 0xAD, 0xDE };

// LoRaWAN NwkSKey, network session key 
// Use this key for The Things Network
static const u1_t DEVKEY[16] = { 0xDD, 0x7D, 0xBD, 0xDD, 0x6F, 0x04, 0xF7, 0xDD, 0xDD, 0x4D, 0xE8, 0xAC, 0xEA, 0x44, 0x1F, 0x47 };

// LoRaWAN AppSKey, application session key
// Use this key to get your data decrypted by The Things Network
static const u1_t ARTKEY[16] = { 0x01, 0xF2, 0xE3, 0x64, 0x75, 0x95, 0x06, 0x57, 0x6F, 0x06, 0x1C, 0x58, 0x2C, 0x2D, 0xCD, 0xAA };

// LoRaWAN end-device address (DevAddr)
// See http://thethingsnetwork.org/wiki/AddressSpace
static const u4_t DEVADDR = 0x26031F39; // <-- Change this address for every node! ESP8266 node 0x01

unsigned long previousMillis = 0;
uint8_t mydata[8] = {0};
static osjob_t sendjob;

uint16_t light_val = 0;
uint16_t pressure_val = 0;
uint16_t temp_val = 0;
uint16_t altitude_val = 0;

/**
 * Displays some basic information on this sensor from the unified
 * sensor API sensor_t type (see Adafruit_Sensor for more information)
 */
void displaySensorDetails(void)
{
    sensor_t sensor;
    bmp.getSensor(&sensor);
    Serial.println("------------------------------------");
    Serial.print  ("Sensor:       "); Serial.println(sensor.name);
    Serial.print  ("Driver Ver:   "); Serial.println(sensor.version);
    Serial.print  ("Unique ID:    "); Serial.println(sensor.sensor_id);
    Serial.print  ("Max Value:    "); Serial.print(sensor.max_value); Serial.println(" hPa");
    Serial.print  ("Min Value:    "); Serial.print(sensor.min_value); Serial.println(" hPa");
    Serial.print  ("Resolution:   "); Serial.print(sensor.resolution); Serial.println(" hPa");  
    Serial.println("------------------------------------");
    Serial.println("");
    delay(500);
    
    tsl.getSensor(&sensor);
    Serial.println("------------------------------------");
    Serial.print  ("Sensor:       "); Serial.println(sensor.name);
    Serial.print  ("Driver Ver:   "); Serial.println(sensor.version);
    Serial.print  ("Unique ID:    "); Serial.println(sensor.sensor_id);
    Serial.print  ("Max Value:    "); Serial.print(sensor.max_value); Serial.println(" lux");
    Serial.print  ("Min Value:    "); Serial.print(sensor.min_value); Serial.println(" lux");
    Serial.print  ("Resolution:   "); Serial.print(sensor.resolution); Serial.println(" lux");  
    Serial.println("------------------------------------");
    Serial.println("");
    delay(500);
}

/**
 * 
 * 
 * 
 */
void configureSensor(void)
{
    /* You can also manually set the gain or enable auto-gain support */
    // tsl.setGain(TSL2561_GAIN_1X);      /* No gain ... use in bright light to avoid sensor saturation */
    // tsl.setGain(TSL2561_GAIN_16X);     /* 16x gain ... use in low light to boost sensitivity */
    tsl.enableAutoRange(true);            /* Auto-gain ... switches automatically between 1x and 16x */
    
    /* Changing the integration time gives you better sensor resolution (402ms = 16-bit data) */
    tsl.setIntegrationTime(TSL2561_INTEGRATIONTIME_13MS);      /* fast but low resolution */
    // tsl.setIntegrationTime(TSL2561_INTEGRATIONTIME_101MS);  /* medium resolution and speed   */
    // tsl.setIntegrationTime(TSL2561_INTEGRATIONTIME_402MS);  /* 16-bit data but slowest conversions */
    
    /* Update these values depending on what you've set above! */  
    Serial.println("------------------------------------");
    Serial.print  ("Gain:         "); Serial.println("Auto");
    Serial.print  ("Timing:       "); Serial.println("13 ms");
    Serial.println("------------------------------------");
}

/**
 * provide application router ID (8 bytes, LSBF) 
 */
void os_getArtEui (u1_t* buf)
{
    memcpy(buf, APPEUI, 8);
}

/** 
 * provide device ID (8 bytes, LSBF)
 */
void os_getDevEui (u1_t* buf)
{
    memcpy(buf, DEVEUI, 8);
}

/**
 * provide device key (16 bytes) 
 */
void os_getDevKey (u1_t* buf)
{
    memcpy(buf, DEVKEY, 16);
}

// Pin mapping
// XXX We have to see whether all these pins are really used
// if not, we can use them for real sensor work.
lmic_pinmap pins = {
    .nss = 15,          // Make D8/GPIO15, is nSS on ESP8266
    .rxtx = 2,          // D4/GPIO2. For placeholder only,
                        // Do not connected on RFM92/RFM95
    .rst = 0,           // Make D0/GPIO16, Needed on RFM92/RFM95? (probably not)
    .dio = {5, 4, 3},   // Specify pin numbers for DIO0, 1, 2
                        // D1/GPIO5,D2/GPIO4,D3/GPIO3 are usable pins on ESP8266
                        // NOTE: D3 not really usable when UART not connected
                        // As it is used during bootup and will probably not boot.
                        // Leave D3 Pin unconnected for sensor to work
};

/**
 * 
 * 
 */
void onEvent (ev_t ev)
{
    //debug_event(ev);
    
    switch(ev) {
        // scheduled data sent (optionally data received)
        // note: this includes the receive window!
        case EV_TXCOMPLETE:
            // use this event to keep track of actual transmissions
            Serial.print("Event EV_TXCOMPLETE, time: ");
            Serial.println(millis() / 1000);
            if (LMIC.dataLen) { // data received in rx slot after tx
                //debug_buf(LMIC.frame+LMIC.dataBeg, LMIC.dataLen);
                Serial.println("Data Received!");
            }
            break;
        default:
            break;
    }
}
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

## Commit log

2015-08-29 Adiciona README.md e projeto de umidade e temperatura
    [esp8266_esp_01_ftdi_logic_level_converter_dht11.fzz]
2015-09-04 Adicionado hello led
    [esp8266_esp_01_ftdi_logic_level_converter_.fzz]
2015-09-27 Add micropython led code
2015-11-18 Update wiring guide to led
    [esp8266_esp_01_ftdi_logic_level_converter_.fzz]
2015-11-24 Versao base para o script de teste ESP+pir+NodeMCU+Lua.
2015-11-30 Melhorias no processo de utilizacao do script, agora e possivel salvar script como init.lua que o modulo carregara automaticamente no inicio.
2015-12-02 Codigo envia um topico na mudanca de estado.
2017-08-19 Medição de Corrente de elétrica
    Medição de Correntes de no máximo 20A através da entrada analógica do ESP8266 e envio ao servidor MQTT através dos tópicos subscritos.
2017-08-22 Moved folders
    [esp8266_esp_01_ftdi_logic_level_converter_.fzz, esp8266_esp_01_ftdi_logic_level_converter_dht11.fzz]
2017-08-24 Placas de Monitoramento e Comando
    [Rele-board.brd, Rele-board.sch, TBD-board.brd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]
2017-08-27 As built
    [Rele-board.brd, Rele-board.sch, TBD-board.brd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]
2017-09-29 Traducao de alguns termos e breve descricao de alguns itens.
2017-10-05 Inserido tópicos e currentrms
2017-10-14 API1.0 de ponta a ponta MQTT-SQLITE-API
2017-11-01 Adicionando WIP da aplicacao Lora para envio de dados dos sensore BMP085 e TSL2561.
